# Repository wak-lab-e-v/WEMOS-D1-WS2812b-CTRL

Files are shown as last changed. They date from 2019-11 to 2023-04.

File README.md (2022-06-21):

# WEMOS D1 (ESP8266) LED Controller

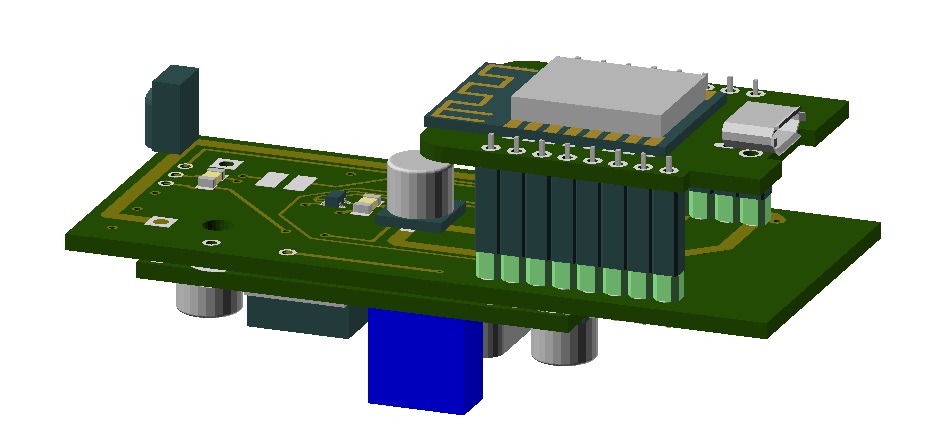
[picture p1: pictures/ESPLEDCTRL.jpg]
Bild


Controller for WS2812B LED Strips / Panels / i.e. , optimized for the https://github.com/Aircoookie/WLED projekt

*Targets:*

- compact in a 3D printed case
- DC via hollow plug and 2A Step Down converter
- alternately over JST 3-pin (INPUT, 5V, data ignored)
- WEMOS D1 as controller
- diode protection for WEMOS D1 5V input
- Stabi-Elco in the 5V branch 
- Level Shift via 74HCT1G08GW
- Push button direct to controler (typically used as on/off via software)
- Infrarot support for IR-Remote
- PCB with Wemos-D1 und Step Down converter side-by-side

*LED Strip:*

- WS2812B-compatible RGB(W) led strip to GPIO2 / D2
- optional support for GPIO16 / D0 via solder bridge 
- level-shift via 74HCT1G08GW
- output via solder pads, JST 3-pin

*Push button:*

- a push button is connected to GPIO0 / D3

*Infrared:*

- recommended: TSOP38238
- Pinout: 2.5 V to 5.5 V, GND, Signal
- Signal to GPIO4 / D2 (can be changed in NpbWrapper.h)

*PCB:*

- D2 to Infrared solder pad
- D3 to button solder pad
- D4 to solder bridge/switch, level shifter, led signal solder pad
- D0 to solder bridge/switch, level shifter, led signal solder pad

*Wemos D1 Pinout:*

- A0	Analoger Eingang, max 3,3V	A0
- D0	IO	GPIO16
- D1	IO	GPIO5, SCL
- D2	IO	GPIO4, SDA
- D3	IO	GPIO0, 10k Pull-up
- D4	IO	GPIO2, 10k Pull-up, Onboard LED
- D5	IO  GPIO14, SCK	
- D6	IO	GPIO12, MISO
- D7	IO	GPIO13, MOSI
- D8	IO	GPIO15, 10k Pull-down, SS (Slave Select)
- GND
- 5V	(unprotected)
- 3V3	3,3V (from onboard step-down)

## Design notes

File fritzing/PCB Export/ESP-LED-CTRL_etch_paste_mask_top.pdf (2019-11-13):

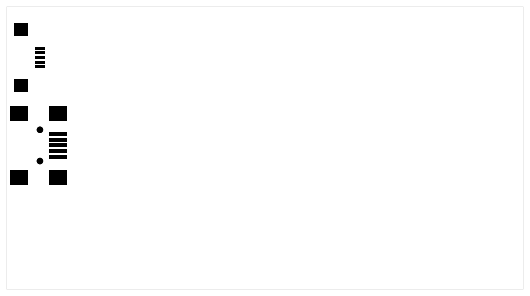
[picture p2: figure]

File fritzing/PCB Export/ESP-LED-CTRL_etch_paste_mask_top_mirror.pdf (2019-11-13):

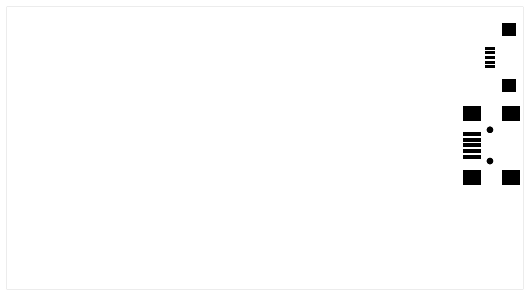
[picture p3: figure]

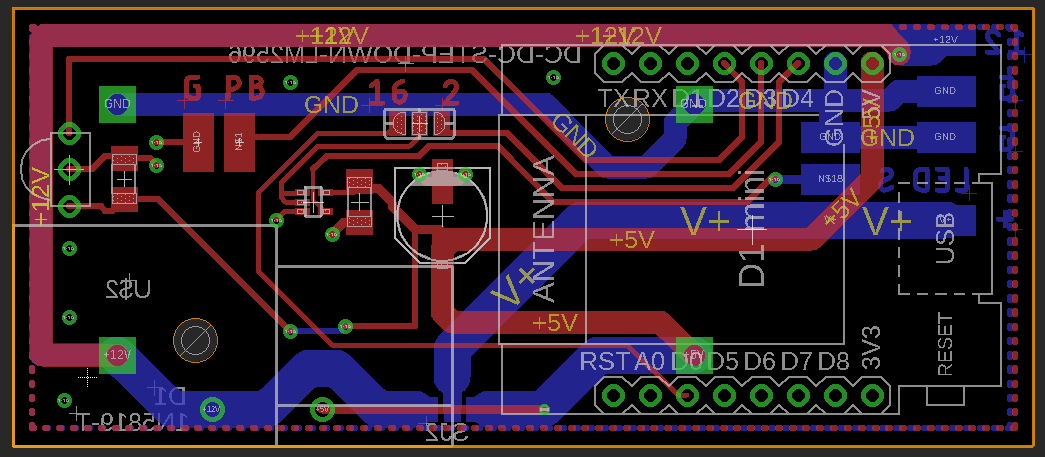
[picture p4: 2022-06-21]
pictures/Leiterplatte.PNG

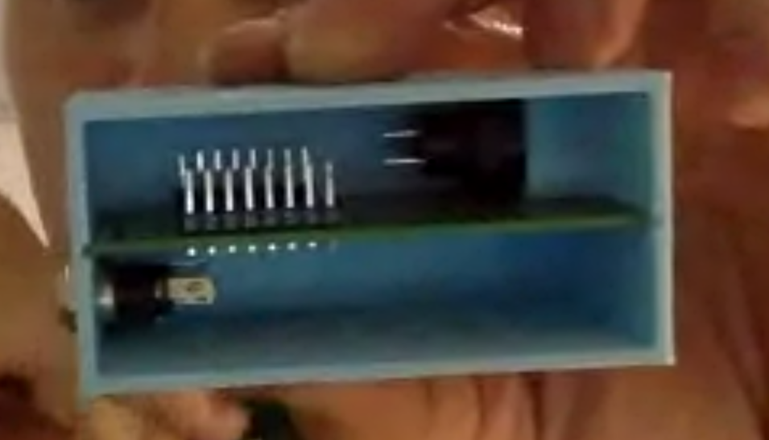
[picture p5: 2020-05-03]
pictures/Gehäuse2.png

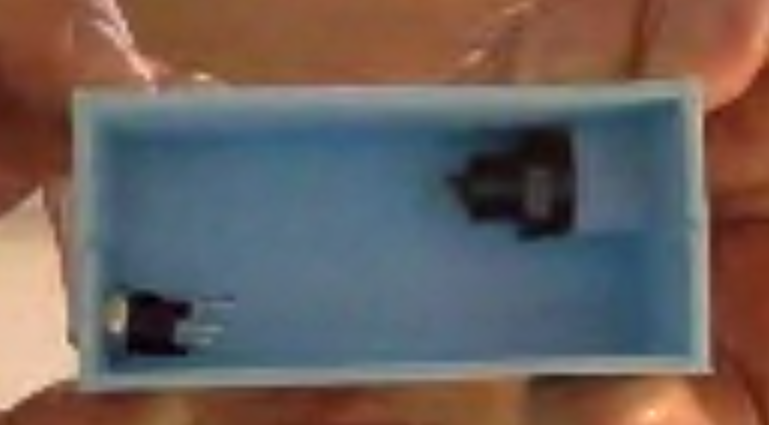
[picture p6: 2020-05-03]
pictures/Gehäuse.png

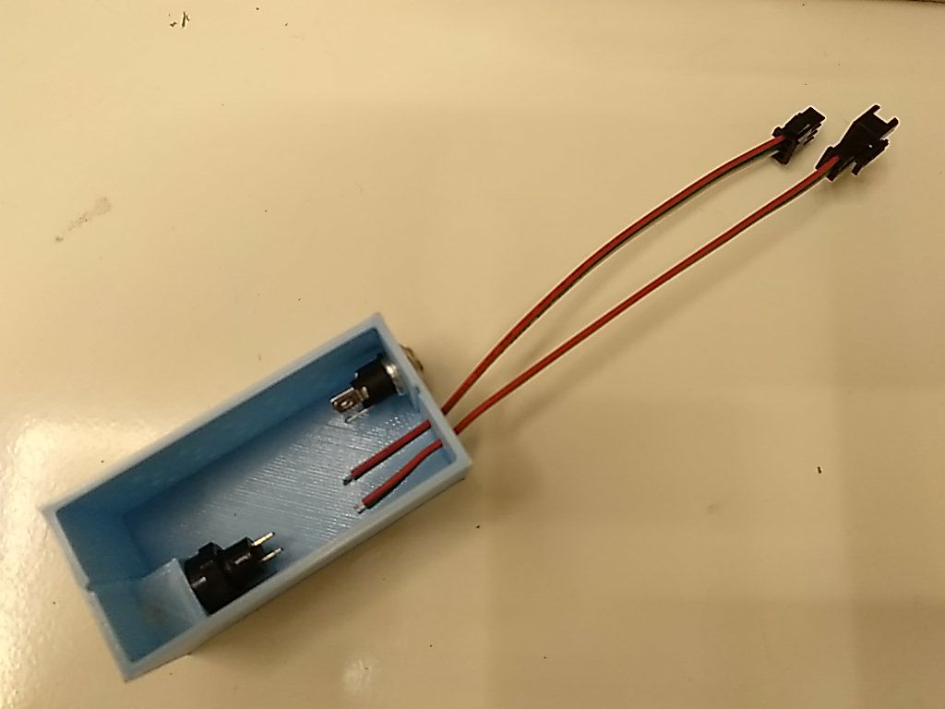
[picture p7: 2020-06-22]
pictures/Gehäuse.jpg

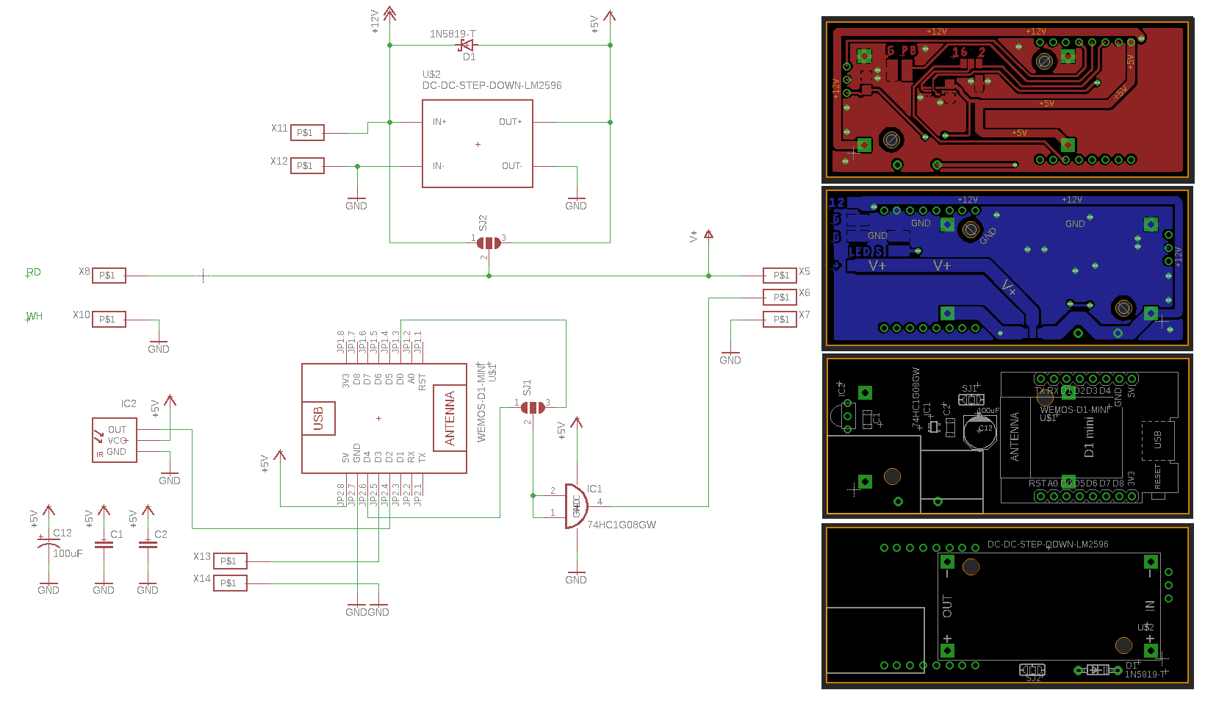
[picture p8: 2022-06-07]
Schaltplan.png

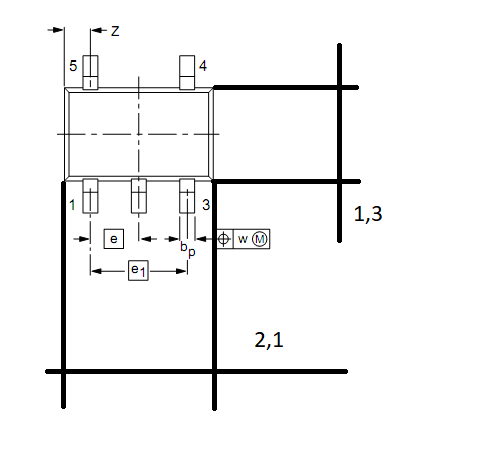
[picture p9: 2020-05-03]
Datasheet/74HCT1G08GW.png

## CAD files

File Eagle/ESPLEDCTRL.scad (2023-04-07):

Detailgrad = 24; 
$fn=Detailgrad; 
holewithorigin=false; 
EnableVias=true; 
EnableParts=true; 
EnableWires=true;   // Disable for smaler export file
EnablePolygones=true;  // Disable for smaler export file
HideAutogeneratedParts=true;  // Disable yellow boxes
EnableSoldermask=false;  // Disable for smaler export file

module ESPLEDCTRL(){
	board_thickness = 1.600;
	eta = 0.2;
	board_size = [70.168,30.163];
	board_origin = [0,0];
	board_polygons = [[[-5.080,-4.763],[65.088,-4.763],[65.088,25.400],[-5.080,25.400]]];
	translate([0,0,0]) union()   // PCB whith parts and text
	{
		color("#265004")linear_extrude(height=board_thickness,center=false, convexity=10)
		union()  // PCB 
		{
			difference() // PCB and holes 
			{
				translate(board_origin)  polygon(points = board_polygons[0]); //Board
				if (Detailgrad > 9) // Drill part holes 
				{
					translate([7.429,2.540])circle(r=1.500,$fn=$fn); //hole
					translate([37.148,17.780])circle(r=1.500,$fn=$fn); //hole
					translate([16.192,-2.223])circle(r=0.550,$fn=$fn); //DO41-7.6 A
					translate([8.572,-2.223])circle(r=0.550,$fn=$fn); //DO41-7.6 C
					translate([-1.270,16.828])circle(r=0.500,$fn=$fn); //TSOP38 1
					translate([-1.270,14.288])circle(r=0.500,$fn=$fn); //TSOP38 2
					translate([-1.270,11.748])circle(r=0.500,$fn=$fn); //TSOP38 3
					translate([36.195,21.590])circle(r=0.508,$fn=$fn); //MA08-1 1
					translate([38.735,21.590])circle(r=0.508,$fn=$fn); //MA08-1 2
					translate([41.275,21.590])circle(r=0.508,$fn=$fn); //MA08-1 3
					translate([43.815,21.590])circle(r=0.508,$fn=$fn); //MA08-1 4
					translate([46.355,21.590])circle(r=0.508,$fn=$fn); //MA08-1 5
					translate([48.895,21.590])circle(r=0.508,$fn=$fn); //MA08-1 6
					translate([51.435,21.590])circle(r=0.508,$fn=$fn); //MA08-1 7
					translate([53.975,21.590])circle(r=0.508,$fn=$fn); //MA08-1 8
					translate([36.195,-1.270])circle(r=0.508,$fn=$fn); //MA08-1 1
					translate([38.735,-1.270])circle(r=0.508,$fn=$fn); //MA08-1 2
					translate([41.275,-1.270])circle(r=0.508,$fn=$fn); //MA08-1 3
					translate([43.815,-1.270])circle(r=0.508,$fn=$fn); //MA08-1 4
					translate([46.355,-1.270])circle(r=0.508,$fn=$fn); //MA08-1 5
					translate([48.895,-1.270])circle(r=0.508,$fn=$fn); //MA08-1 6
					translate([51.435,-1.270])circle(r=0.508,$fn=$fn); //MA08-1 7
					translate([53.975,-1.270])circle(r=0.508,$fn=$fn); //MA08-1 8
					translate([36.195,-1.270])circle(r=0.500,$fn=$fn); //WEMOS-D1-MINI JP1.1
					translate([38.735,-1.270])circle(r=0.500,$fn=$fn); //WEMOS-D1-MINI JP1.2
					translate([41.275,-1.270])circle(r=0.500,$fn=$fn); //WEMOS-D1-MINI JP1.3
					translate([43.815,-1.270])circle(r=0.500,$fn=$fn); //WEMOS-D1-MINI JP1.4
					translate([46.355,-1.270])circle(r=0.500,$fn=$fn); //WEMOS-D1-MINI JP1.5
					translate([48.895,-1.270])circle(r=0.500,$fn=$fn); //WEMOS-D1-MINI JP1.6
					translate([51.435,-1.270])circle(r=0.500,$fn=$fn); //WEMOS-D1-MINI JP1.7
					translate([53.975,-1.270])circle(r=0.500,$fn=$fn); //WEMOS-D1-MINI JP1.8
					translate([36.195,21.590])circle(r=0.500,$fn=$fn); //WEMOS-D1-MINI JP2.1
					translate([38.735,21.590])circle(r=0.500,$fn=$fn); //WEMOS-D1-MINI JP2.2
					translate([41.275,21.590])circle(r=0.500,$fn=$fn); //WEMOS-D1-MINI JP2.3
					translate([43.815,21.590])circle(r=0.500,$fn=$fn); //WEMOS-D1-MINI JP2.4
					translate([46.355,21.590])circle(r=0.500,$fn=$fn); //WEMOS-D1-MINI JP2.5
					translate([48.895,21.590])circle(r=0.500,$fn=$fn); //WEMOS-D1-MINI JP2.6
					translate([51.435,21.590])circle(r=0.500,$fn=$fn); //WEMOS-D1-MINI JP2.7
					translate([53.975,21.590])circle(r=0.500,$fn=$fn); //WEMOS-D1-MINI JP2.8
					translate([2.095,1.524])circle(r=0.750,$fn=$fn); //DC-DC-STEP-DOWN-LM2596 IN+
					translate([2.095,18.796])circle(r=0.750,$fn=$fn); //DC-DC-STEP-DOWN-LM2596 IN-
					translate([41.720,1.524])circle(r=0.750,$fn=$fn); //DC-DC-STEP-DOWN-LM2596 OUT+
					translate([41.720,18.796])circle(r=0.750,$fn=$fn); //DC-DC-STEP-DOWN-LM2596 OUT-
					if (EnableVias && (Detailgrad > 12)) 
 					union() // Vias 
					{
						translate([31.433,-2.223])circle(r=0.175,$fn=$fn); //via
						translate([13.970,3.175])circle(r=0.300,$fn=$fn); //via
						translate([17.780,3.493])circle(r=0.300,$fn=$fn); //via
						translate([55.880,22.225])circle(r=0.300,$fn=$fn); //via
						translate([4.763,14.605])circle(r=0.300,$fn=$fn); //via
						translate([4.763,16.192])circle(r=0.300,$fn=$fn); //via
						translate([26.035,13.970])circle(r=0.300,$fn=$fn); //via
						translate([22.860,13.970])circle(r=0.300,$fn=$fn); //via
						translate([13.018,10.795])circle(r=0.300,$fn=$fn); //via
						translate([16.828,9.843])circle(r=0.300,$fn=$fn); //via
						translate([-1.588,-1.588])circle(r=0.300,$fn=$fn); //via
						translate([-1.270,8.890])circle(r=0.300,$fn=$fn); //via
						translate([-1.270,4.128])circle(r=0.300,$fn=$fn); //via
						translate([13.970,20.320])circle(r=0.300,$fn=$fn); //via
						translate([32.068,20.637])circle(r=0.300,$fn=$fn); //via
						translate([47.308,13.652])circle(r=0.300,$fn=$fn); //via
					} // End Vias
				} // end Drill part holes
			} //end difference() PCB and holes 
			if (holewithorigin) 
			{
				//Print a little cross in the PCB holes 
			}
		} //end union() // PCB 
		if (Detailgrad > 10) color("#DFDDE0",1) translate([0,0,board_thickness-0.017]) linear_extrude(height=0.040,center=false, convexity=10) difference()  { 
	  union() { 
					translate([2.540,12.253]) rotate([0,0,90.000]) square([1.600,1.800], center = true); //C1206 1
			translate([2.540,15.053]) rotate([0,0,90.000]) square([1.600,1.800], center = true); //C1206 2
			translate([18.733,13.465]) rotate([0,0,270.000]) square([1.600,1.800], center = true); //C1206 1
			translate([18.733,10.665]) rotate([0,0,270.000]) square([1.600,1.800], center = true); //C1206 2
			translate([24.448,8.713]) rotate([0,0,270.000]) square([3.000,1.400], center = true); //PANASONIC_D +
			translate([24.448,13.513]) rotate([0,0,270.000]) square([3.000,1.400], center = true); //PANASONIC_D -
			translate([16.192,-2.223]) circle(r=0.850,$fn=$fn);
			translate([8.572,-2.223]) circle(r=0.850,$fn=$fn);
			translate([14.758,12.715]) rotate([0,0,270.000]) square([0.400,0.900], center = true); //SOT353 1
			translate([14.758,12.065]) rotate([0,0,270.000]) square([0.400,0.900], center = true); //SOT353 2
			translate([14.758,11.415]) rotate([0,0,270.000]) square([0.400,0.900], center = true); //SOT353 3
			translate([16.358,11.415]) rotate([0,0,270.000]) square([0.400,0.900], center = true); //SOT353 4
			translate([16.358,12.715]) rotate([0,0,270.000]) square([0.400,0.900], center = true); //SOT353 5
			translate([-1.270,16.828]) circle(r=0.754,$fn=$fn);
			translate([-1.270,14.288]) circle(r=0.754,$fn=$fn);
			translate([-1.270,11.748]) circle(r=0.754,$fn=$fn);
			translate([24.384,17.463]) rotate([0,0,180.000]) square([1.168,1.600], center = true); //SJ_2 1
			translate([22.860,17.463]) rotate([0,0,180.000]) square([1.168,1.600], center = true); //SJ_2 2
			translate([21.336,17.463]) rotate([0,0,180.000]) square([1.168,1.600], center = true); //SJ_2 3
			translate([36.195,21.590]) rotate([0,0,180.000]) EaglePad([1.524,3.048], 100); //MA08-1 1
			translate([38.735,21.590]) rotate([0,0,180.000]) EaglePad([1.524,3.048], 100); //MA08-1 2
			translate([41.275,21.590]) rotate([0,0,180.000]) EaglePad([1.524,3.048], 100); //MA08-1 3
			translate([43.815,21.590]) rotate([0,0,180.000]) EaglePad([1.524,3.048], 100); //MA08-1 4
			translate([46.355,21.590]) rotate([0,0,180.000]) EaglePad([1.524,3.048], 100); //MA08-1 5
			translate([48.895,21.590]) rotate([0,0,180.000]) EaglePad([1.524,3.048], 100); //MA08-1 6
			translate([51.435,21.590]) rotate([0,0,180.000]) EaglePad([1.524,3.048], 100); //MA08-1 7
			translate([53.975,21.590]) rotate([0,0,180.000]) EaglePad([1.524,3.048], 100); //MA08-1 8
			translate([36.195,-1.270]) rotate([0,0,180.000]) EaglePad([1.524,3.048], 100); //MA08-1 1
			translate([38.735,-1.270]) rotate([0,0,180.000]) EaglePad([1.524,3.048], 100); //MA08-1 2
			translate([41.275,-1.270]) rotate([0,0,180.000]) EaglePad([1.524,3.048], 100); //MA08-1 3
			translate([43.815,-1.270]) rotate([0,0,180.000]) EaglePad([1.524,3.048], 100); //MA08-1 4
			translate([46.355,-1.270]) rotate([0,0,180.000]) EaglePad([1.524,3.048], 100); //MA08-1 5
			translate([48.895,-1.270]) rotate([0,0,180.000]) EaglePad([1.524,3.048], 100); //MA08-1 6
			translate([51.435,-1.270]) rotate([0,0,180.000]) EaglePad([1.524,3.048], 100); //MA08-1 7
			translate([53.975,-1.270]) rotate([0,0,180.000]) EaglePad([1.524,3.048], 100); //MA08-1 8
			translate([36.195,-1.270]) circle(r=0.754,$fn=$fn);
			translate([38.735,-1.270]) circle(r=0.754,$fn=$fn);
			translate([41.275,-1.270]) circle(r=0.754,$fn=$fn);
			translate([43.815,-1.270]) circle(r=0.754,$fn=$fn);
			translate([46.355,-1.270]) circle(r=0.754,$fn=$fn);
			translate([48.895,-1.270]) circle(r=0.754,$fn=$fn);
			translate([51.435,-1.270]) circle(r=0.754,$fn=$fn);
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

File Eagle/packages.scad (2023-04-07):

Detailgrad = Detailgrad ? Detailgrad : 10;
function defined(a) = (a != undef);

module 1X08_CLEANBIG(Name="",Value="",Library="pinhead") {LSTA(n=8);}
module MA08_1(Name="",Value="",Library="con-lstb") {LSTB(n=8);}
module PANASONIC_D(Name="",Value="",Library="") {  color("DarkSlateGray") translate([0,0,1/2]) cube([6.6,6.6,1], center = true); color("silver") Phased_cylinder(5.8,6.3/2,6.3/2);}
module C1206(Name="",Value="",Library="") {C_SMD([3.2,1.6,0.8]);}
// Generic
module SOT353(Name="",Value="",Library="")
{
  dim = [2,1.25,1];
  rotate([0,0,180]){
  color("DarkSlateGray") cubepart(dim); 
  rotate([0,0,180])  SMD_PIN(size=dim, pinnumber = 1, pitch=0.65, pinlength=0.425, pinheight = 0.4 );
  rotate([0,0,180])  SMD_PIN(size=dim, pinnumber = 2, pitch=0.65, pinlength=0.425, pinheight = 0.4 );
  rotate([0,0,180])  SMD_PIN(size=dim, pinnumber = 3, pitch=0.65, pinlength=0.425, pinheight = 0.4 );
  SMD_PIN(size=dim, pinnumber = 1, pitch=0.65, pinlength=0.425, pinheight = 0.4 );
  SMD_PIN(size=dim, pinnumber = 3, pitch=0.65, pinlength=0.425, pinheight = 0.4 );
  }
}

module ESP_12(Name="",Value="",Library=""){ // Eagle Adafruit
	board_thicknessA = 1.000000;
	eta = 0.2;
  $fn = Detailgrad;
	rotate([0,0,90]) translate([-12.065+1,-8.09625,0]) union(){   // PCB whith parts and text
		color("DarkSlateGray")linear_extrude(height=board_thicknessA,center=false, convexity=10)
		polygon(points = [[0,16.192500],[24.13,16.1925],[24.13,0],[0,0]]); //Board
    
    color("Goldenrod",0.7) translate([0,0,board_thicknessA-0.017]) linear_extrude(height=0.035,center=false, convexity=10) difference()  { 
	  union() { 
					translate([17.463,3.004]) rotate([0,0,270.000]) square([1.092,1.397], center = true); //LED0805 A
			translate([17.463,1.124]) rotate([0,0,270.000]) square([1.092,1.397], center = true); //LED0805 K
			translate([1.558,1.318])square([1.270,2.540], center = true); //SMD1,27-2,54 1
			translate([3.558,1.318])square([1.270,2.540], center = true); //SMD1,27-2,54 1
			translate([5.558,1.318])square([1.270,2.540], center = true); //SMD1,27-2,54 1
			translate([7.558,1.318])square([1.270,2.540], center = true); //SMD1,27-2,54 1
			translate([9.558,1.318])square([1.270,2.540], center = true); //SMD1,27-2,54 1
			translate([11.558,1.318])square([1.270,2.540], center = true); //SMD1,27-2,54 1
			translate([13.558,1.318])square([1.270,2.540], center = true); //SMD1,27-2,54 1
			translate([15.558,1.318])square([1.270,2.540], center = true); //SMD1,27-2,54 1
			translate([15.558,14.953])square([1.270,2.540], center = true); //SMD1,27-2,54 1
			translate([13.558,14.953])square([1.270,2.540], center = true); //SMD1,27-2,54 1
			translate([11.558,14.953])square([1.270,2.540], center = true); //SMD1,27-2,54 1
			translate([9.558,14.953])square([1.270,2.540], center = true); //SMD1,27-2,54 1
			translate([7.558,14.953])square([1.270,2.540], center = true); //SMD1,27-2,54 1
			translate([5.558,14.953])square([1.270,2.540], center = true); //SMD1,27-2,54 1
			translate([3.558,14.953])square([1.270,2.540], center = true); //SMD1,27-2,54 1
			translate([1.558,14.953])square([1.270,2.540], center = true); //SMD1,27-2,54 1
		EagleWire([18.891,0.635],[23.336,0.635],width=0.610,$fn=8);
		EagleWire([23.336,0.635],[23.336,3.334],width=0.610,$fn=8);
		EagleWire([23.336,3.334],[20.320,3.334],width=0.610,$fn=8);
		EagleWire([20.320,3.334],[20.320,6.033],width=0.610,$fn=8);
		EagleWire([20.320,6.033],[23.336,6.033],width=0.610,$fn=8);
		EagleWire([23.336,6.033],[23.336,8.731],width=0.610,$fn=8);
		EagleWire([23.336,8.731],[20.320,8.731],width=0.610,$fn=8);
		EagleWire([20.320,8.731],[20.320,11.430],width=0.610,$fn=8);
		EagleWire([20.320,11.430],[23.336,11.430],width=0.610,$fn=8);
		EagleWire([23.336,11.430],[23.336,13.494],width=0.610,$fn=8);
		EagleWire([23.336,13.494],[23.336,15.558],width=0.610,$fn=8);
		EagleWire([23.336,15.558],[18.574,15.558],width=0.610,$fn=8);
		EagleWire([23.336,13.494],[18.574,13.494],width=0.610,$fn=8);
			translate([1.510,15.000]) circle(r=0.453,$fn=Detailgrad);
			translate([3.510,15.000]) circle(r=0.453,$fn=Detailgrad);
			translate([5.510,15.000]) circle(r=0.453,$fn=Detailgrad);
			translate([7.510,15.000]) circle(r=0.453,$fn=Detailgrad);
			translate([9.510,15.000]) circle(r=0.453,$fn=Detailgrad);
			translate([11.510,15.000]) circle(r=0.453,$fn=Detailgrad);
			translate([13.510,15.000]) circle(r=0.453,$fn=Detailgrad);
			translate([15.510,15.000]) circle(r=0.453,$fn=Detailgrad);
			translate([1.525,1.143]) circle(r=0.453,$fn=Detailgrad);
			translate([3.525,1.143]) circle(r=0.453,$fn=Detailgrad);
			translate([5.525,1.143]) circle(r=0.453,$fn=Detailgrad);
			translate([7.525,1.143]) circle(r=0.453,$fn=Detailgrad);
			translate([9.525,1.143]) circle(r=0.453,$fn=Detailgrad);
			translate([11.525,1.143]) circle(r=0.453,$fn=Detailgrad);
			translate([13.525,1.143]) circle(r=0.453,$fn=Detailgrad);
			translate([15.525,1.143]) circle(r=0.453,$fn=Detailgrad);
		}

		}
color("Goldenrod",0.7) translate([0,0,-0.017]) linear_extrude(height=0.035,center=false, convexity=10) difference()  { 
	  union() { 
					translate([1.510,15.000]) circle(r=0.453,$fn=Detailgrad);
			translate([3.510,15.000]) circle(r=0.453,$fn=Detailgrad);
			translate([5.510,15.000]) circle(r=0.453,$fn=Detailgrad);
			translate([7.510,15.000]) circle(r=0.453,$fn=Detailgrad);
			translate([9.510,15.000]) circle(r=0.453,$fn=Detailgrad);
			translate([11.510,15.000]) circle(r=0.453,$fn=Detailgrad);
			translate([13.510,15.000]) circle(r=0.453,$fn=Detailgrad);
			translate([15.510,15.000]) circle(r=0.453,$fn=Detailgrad);
			translate([1.525,1.143]) circle(r=0.453,$fn=Detailgrad);
			translate([3.525,1.143]) circle(r=0.453,$fn=Detailgrad);
			translate([5.525,1.143]) circle(r=0.453,$fn=Detailgrad);
			translate([7.525,1.143]) circle(r=0.453,$fn=Detailgrad);
			translate([9.525,1.143]) circle(r=0.453,$fn=Detailgrad);
			translate([11.525,1.143]) circle(r=0.453,$fn=Detailgrad);
			translate([13.525,1.143]) circle(r=0.453,$fn=Detailgrad);
			translate([15.525,1.143]) circle(r=0.453,$fn=Detailgrad);
    }
    }
		union(){  // parts 
		translate([8.731,8.096,board_thicknessA])rotate([0,0,90])SHIELD12X15();  //CA1 SHIELD12X15
		translate([17.463,2.064,board_thicknessA])rotate([0,0,270])LED0805();  //LED1 LED0805
		}
	} //endunion() 
   module SHIELD12X15() //CA1 SHIELD12X15
	{
	  rotate([0,0,270])
    {
      color ("silver") 
      linear_extrude(2.3) translate([-7.500000,-6.000000,0]) square([  15.000000,12.000000]); //Board
      
      
    }
  }  
  module LED0805(Enable = false)
  {
    rotate([0,0,90]) 
    {  
        color("gray") translate([0,0,0.125/2]) cube([1.2,2,0.125], center = true);
        if (!Enable)
        {    
          color("green") linear_extrude(0.65,scale = 0.9) square([1.2,1.8],center = true);
        }
        else 
        {    
          color("lightgreen") linear_extrude(0.65,scale = 0.9) square([1.2,1.8],center = true);
        } 
    }    
  }


} // end ESP12
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

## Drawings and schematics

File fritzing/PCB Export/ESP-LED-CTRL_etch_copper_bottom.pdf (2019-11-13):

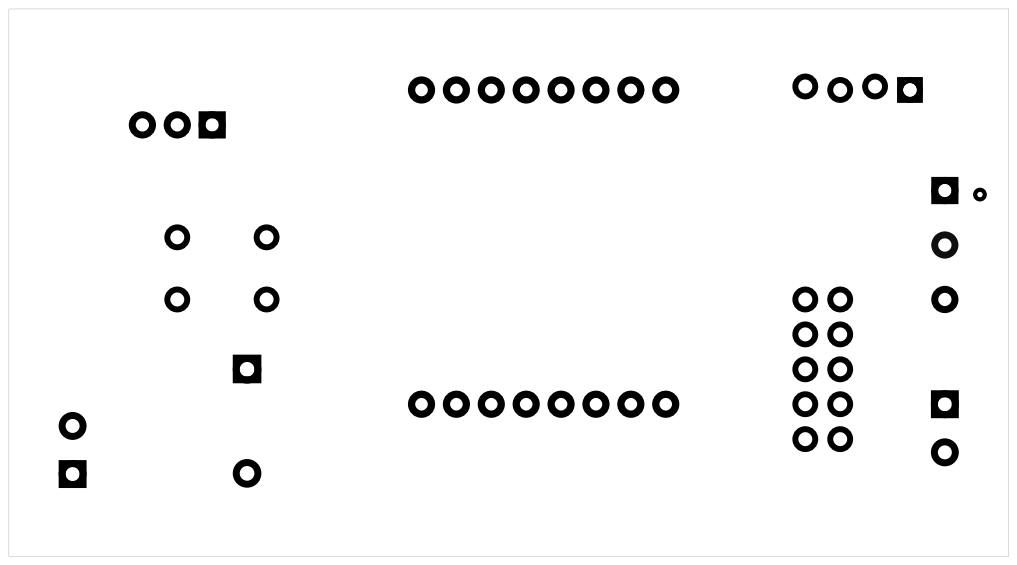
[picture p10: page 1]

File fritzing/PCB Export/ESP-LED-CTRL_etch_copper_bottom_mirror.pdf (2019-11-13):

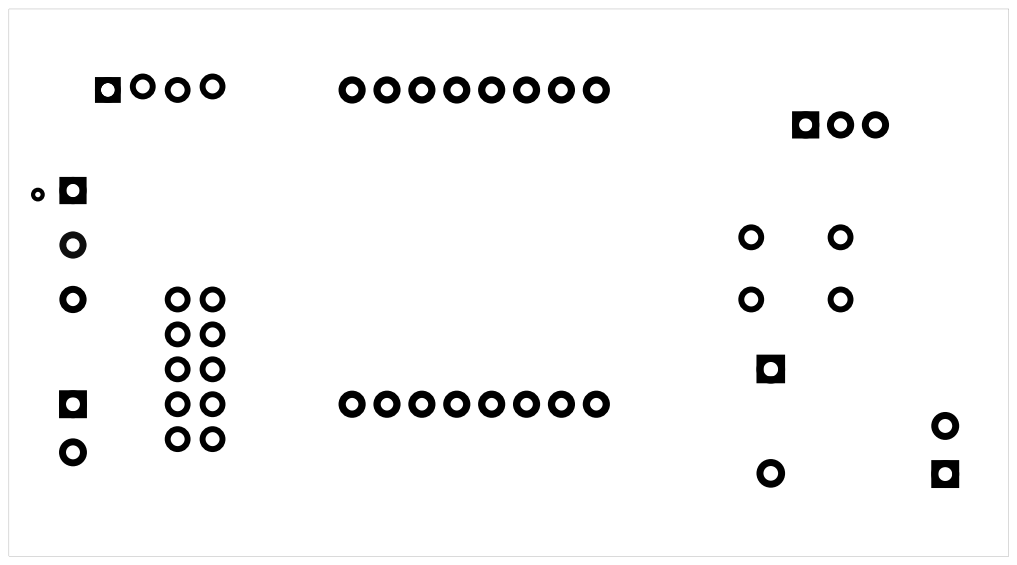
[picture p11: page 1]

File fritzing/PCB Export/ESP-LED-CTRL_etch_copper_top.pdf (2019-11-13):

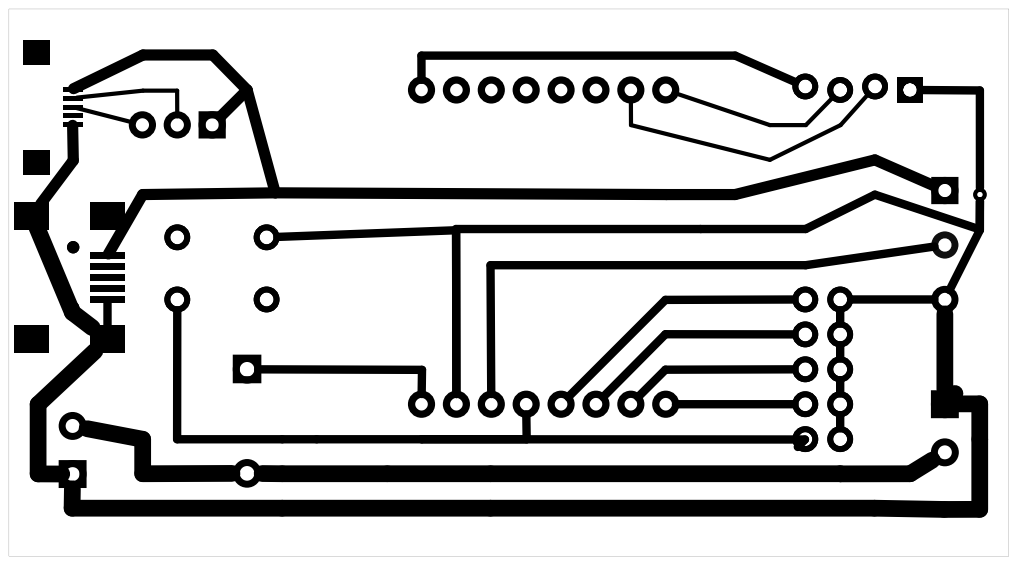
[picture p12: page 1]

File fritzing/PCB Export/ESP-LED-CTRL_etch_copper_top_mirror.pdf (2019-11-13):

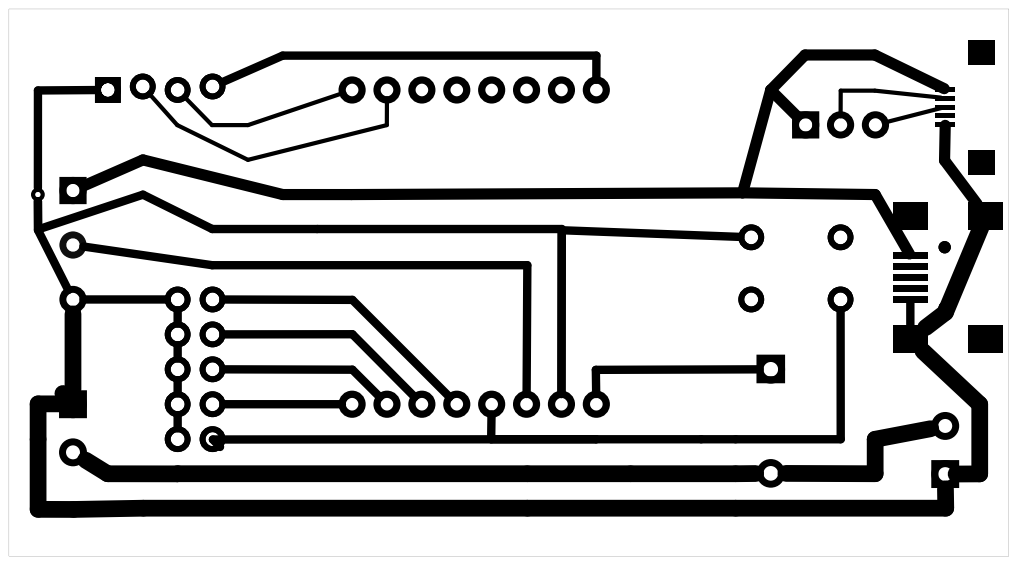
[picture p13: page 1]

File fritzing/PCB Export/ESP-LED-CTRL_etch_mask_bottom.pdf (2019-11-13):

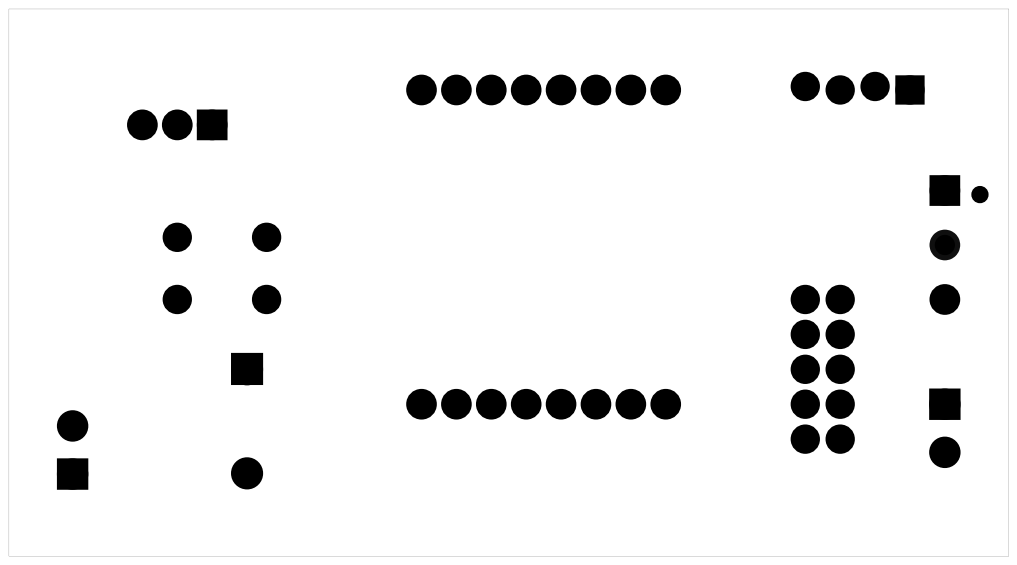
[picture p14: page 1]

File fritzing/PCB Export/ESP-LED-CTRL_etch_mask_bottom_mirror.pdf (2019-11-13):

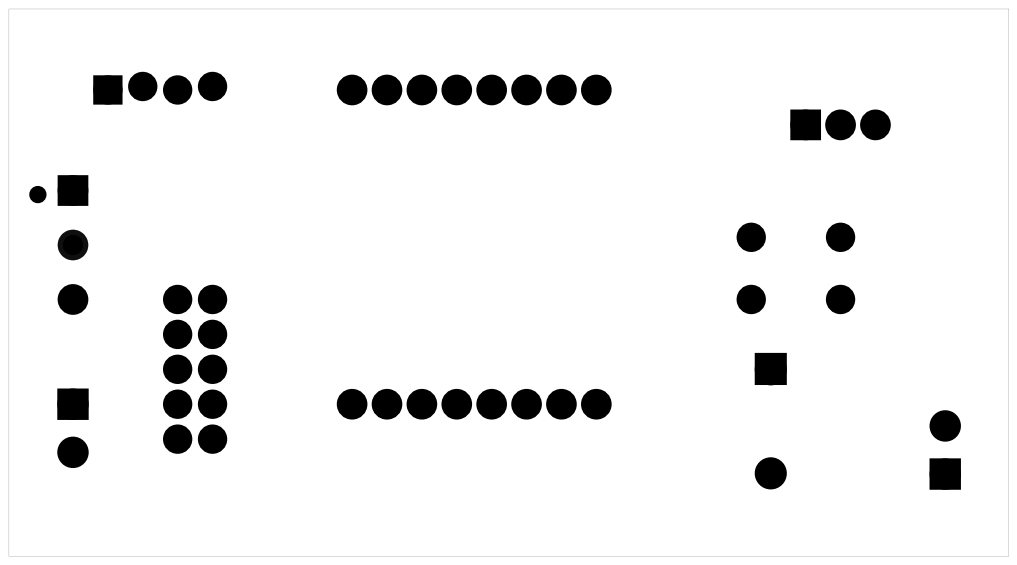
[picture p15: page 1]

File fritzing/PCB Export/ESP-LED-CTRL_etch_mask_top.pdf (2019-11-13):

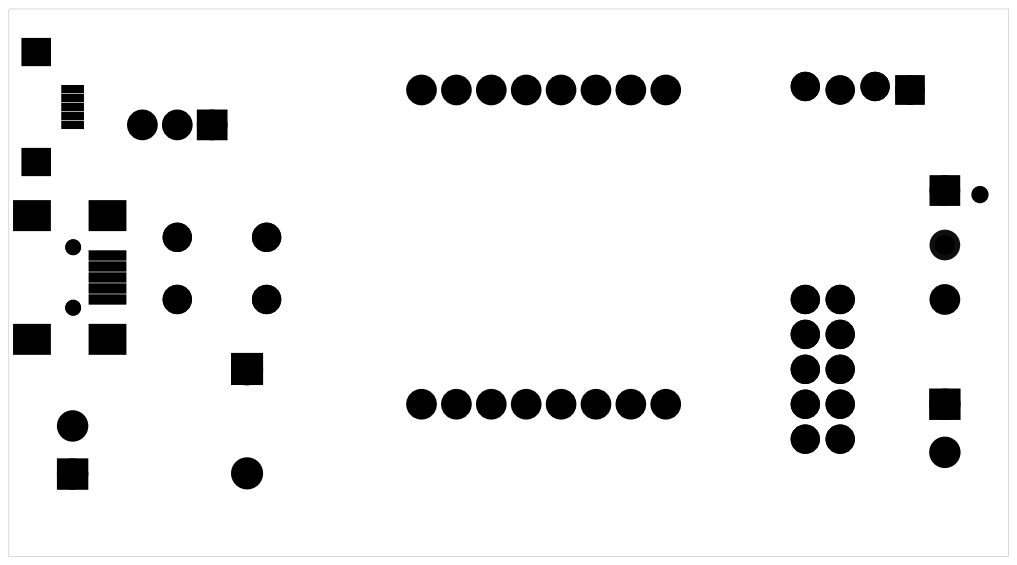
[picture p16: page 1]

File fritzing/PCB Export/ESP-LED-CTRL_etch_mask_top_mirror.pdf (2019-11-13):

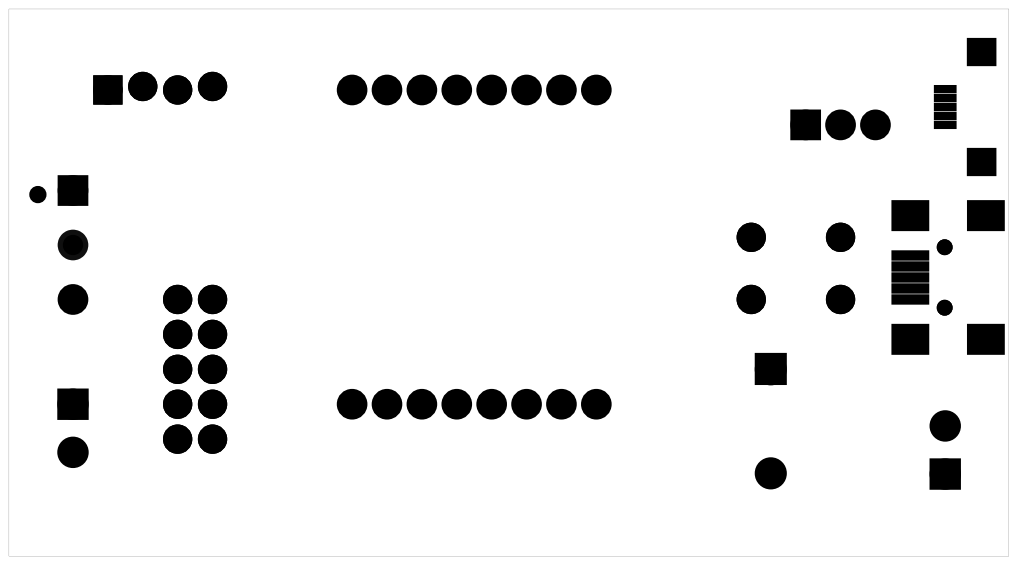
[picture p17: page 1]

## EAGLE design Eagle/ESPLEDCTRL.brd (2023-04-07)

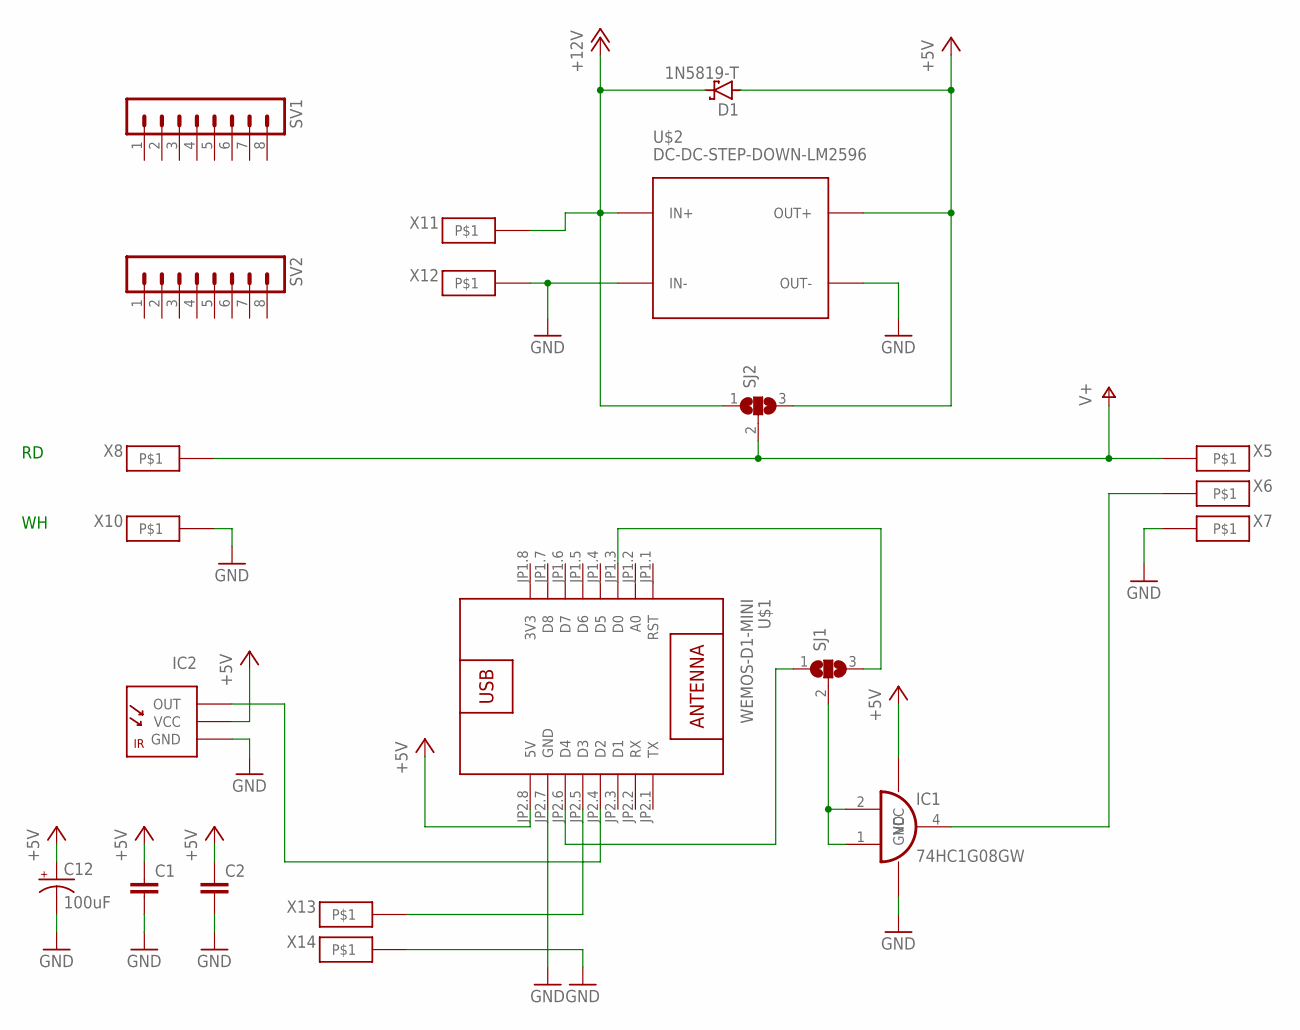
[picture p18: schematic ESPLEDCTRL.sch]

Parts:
C1, C2: C-EUC1206; C1206
C12: 100uF; PANASONIC_D
D1: 1N5819-T; DO41-7.6
IC1: 74HC1G08GW; SOT353
IC2: TSOP382; TSOP38
SJ1, SJ2: SJ2W; SJ_2
SV1, SV2: MA08-1
U$1: WEMOS-D1-MINI
U$2: DC-DC-STEP-DOWN-LM2596
X5, X6, X7, X8, X10, X11, X12, X13, X14: PAD2X4

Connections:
3V3: U$1.JP1.8 (3V3)
+5V: C1.1, C2.1, C12.+, D1.A, IC1.5 (VCC), IC2.3 (VCC), SJ2.3, U$1.JP2.8 (5V), U$2.OUT+
+12V: D1.C, SJ2.1, U$2.IN+, X11.P$1
GND: C1.2, C2.2, C12.-, IC1.3 (GND), IC2.2 (GND), U$1.JP2.7 (GND), U$2.IN-, U$2.OUT-, X7.P$1, X10.P$1, X12.P$1, X14.P$1
unnamed: U$1.JP2.5 (D3), X13.P$1
unnamed: IC2.1 (OUT), U$1.JP2.4 (D2)
unnamed: SJ1.1, U$1.JP2.6 (D4)
unnamed: IC1.1 (I1), IC1.2 (I0), SJ1.2
unnamed: SJ1.3, U$1.JP1.3 (D0)
unnamed: IC1.4 (O), X6.P$1
V+: SJ2.2, X5.P$1, X8.P$1

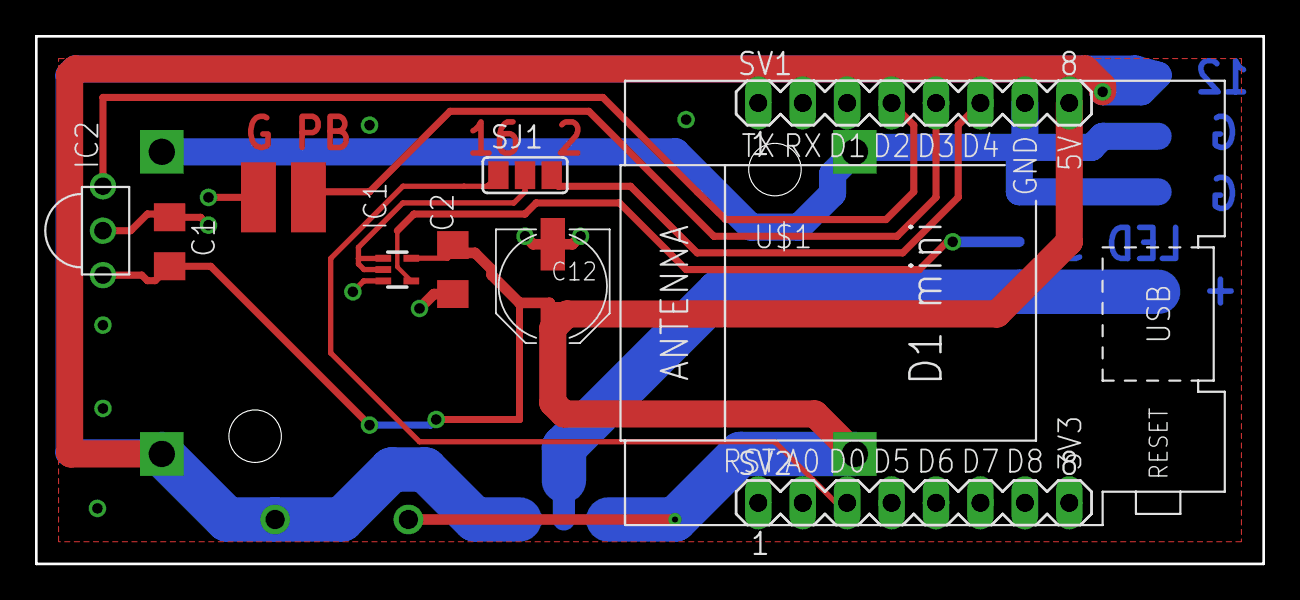
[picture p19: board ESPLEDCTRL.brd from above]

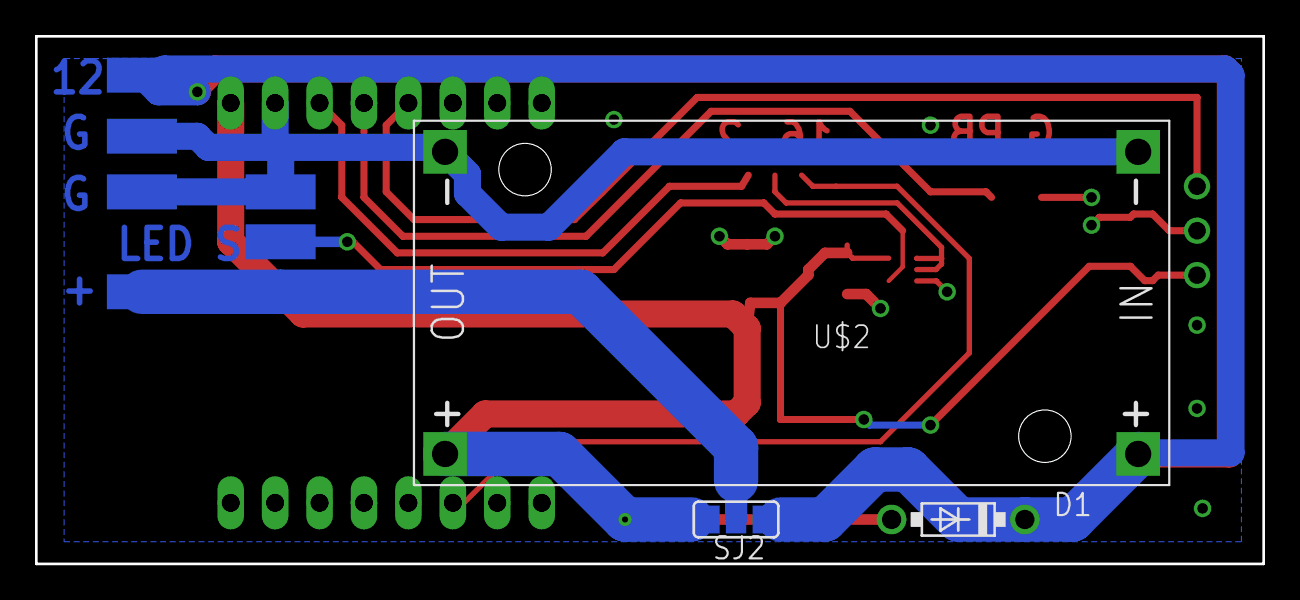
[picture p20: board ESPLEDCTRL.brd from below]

Board: 2 copper layers, 70.2 x 30.2 mm, 21 parts (10 on the bottom side), 10 nets.

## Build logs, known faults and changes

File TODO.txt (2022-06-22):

Board Version 2:

- generell weg von SMD (Shifter und SMD-Elko -> ist schwer zu verlöten )
- PCB darf etwas größer werden -> ggf ESP32 soll mal Platz haben, ggf. auch direkt vorbereiten
- Ausgangswahl D4/D0 entfällt
- mindestens 2 Ausgänge des ESP werden geshiftet (D4 & D0)
- Hinweis WLED-WIKI: LED Data	ESP8266: 1, 2 (3 if <= 100 LEDs), ESP32: 1, 2, 3, 4, 16
- GPIO2 = ESP8266 = D4, on ESP32 based boards use IO16 or G16 or 16
- IR Eingang 
- Button Eingang (D3/IO17)
- Shifter via SN74AHCT125N
- jeder Ausgang hat seine 3 Lötpads
- Lötpads wenn möglich durchkontaktieren
- PB/Pushbutton Abgriff soll auch +5V zur Verfügung stellen (für Touch-Buttons)

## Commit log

2019-11-11 Eine Diode
    [ESPLEDCTRL.brd, ESPLEDCTRL.sch]
2019-11-11 Die Diode
    [ESPLEDCTRL.brd, ESPLEDCTRL.sch]
2019-11-13 some changes
    [ESPLEDCTRL.brd, ESPLEDCTRL.sch]
2019-11-13 Fritzing Files added
    [ESP-LED-CTRL.fzz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]
2019-11-13 minimal changes
    [ESP-LED-CTRL.fzz]
2020-05-03 Alte Version
    [ESPLEDCTRL.brd, ESPLEDCTRL.sch]
2020-05-03 Umbau auf Version 2 beginnt
    [ESPLEDCTRL.brd, ESPLEDCTRL.sch]
2020-06-22 Leiterplatte Anordnung vorbereitet DCDC wandler ist 14mm hoch
    [ESPLEDCTRL.brd, ESPLEDCTRL.scad, ESPLEDCTRL.sch]
2020-06-24 Board fertig gestellt
    [ESPLEDCTRL.brd, ESPLEDCTRL.sch]
2022-06-07 Schaltplan.png aktualisiert, D1 eingefügt
    [ESPLEDCTRL.brd]

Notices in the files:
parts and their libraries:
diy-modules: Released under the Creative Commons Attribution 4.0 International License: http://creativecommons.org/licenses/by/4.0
